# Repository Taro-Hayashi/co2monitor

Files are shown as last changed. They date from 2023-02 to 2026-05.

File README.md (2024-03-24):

# CO2モニター自作キット ビルドガイド
- [キット内容](#キット内容)
- [はんだ付け](#はんだ付け)
- [組み立て](#組み立て)
- [その他](#その他)

## キット内容
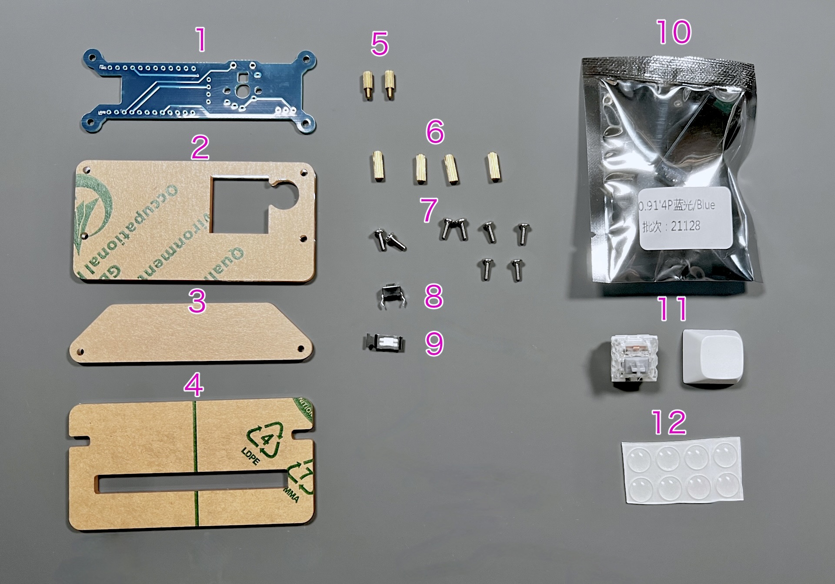
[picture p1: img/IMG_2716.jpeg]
 
||部品名|数||
|-|-|-|-|
|1|メインボード|1||
|2|トッププレート|1||
|3|ボトムプレート|1||
|4|スタンド|1||
|5|スペーサー（短）|2|M2 6mm|
|6|スペーサー（長）|4|M2 9mm|
|7|ねじ|8|M2|
|8|リセットスイッチ|1||
|9|LED|1|SK6812MINI-E|
|10|OLED|1|SSD1306|
|11|キースイッチ|1||
|12|キーキャップ|1||
|13|ゴム足|8||

### キット以外に必要なもの
|部品名|数||
|-|-|-|
|Pro Micro（Micro-B/Type-C）|1||
|MG-812使用CO2ガスセンサアンプキット|1|[秋月電子通商](https://akizukidenshi.com/catalog/g/gK-16446/)|
|USB ケーブル|1|各種キーボードショップ、100円均一など|

## はんだ付け
LEDをメインボード裏面にはんだ付けします。欠けがある方向と折れ曲がった白線が一致するようにしてください。
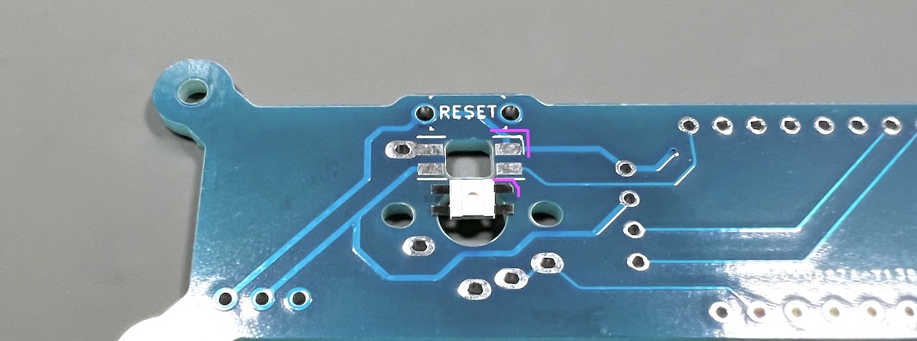
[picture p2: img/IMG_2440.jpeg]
 
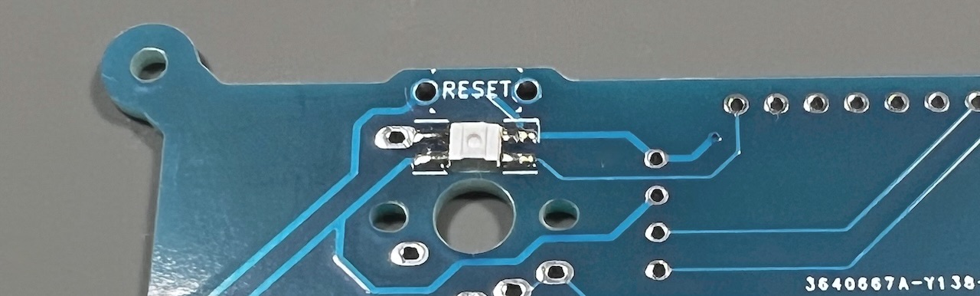
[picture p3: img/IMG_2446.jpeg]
 
リセットスイッチを裏面から差し込みはんだ付けします。
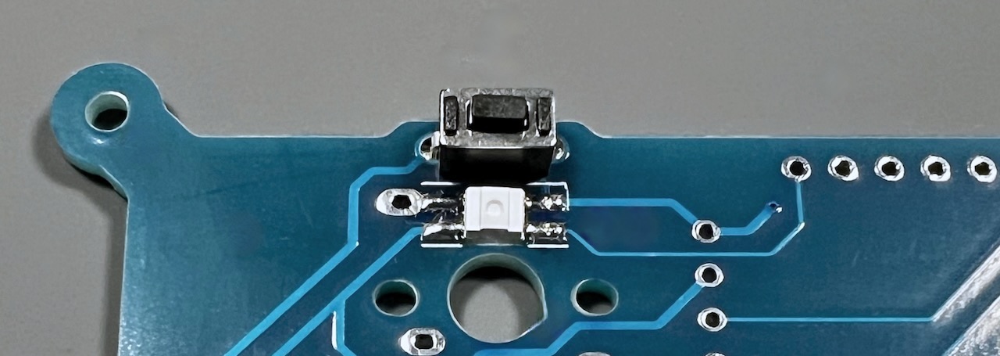
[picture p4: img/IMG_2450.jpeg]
 
Pro Microを付属のピンヘッダーで取り付けて両面をはんだ付けします。
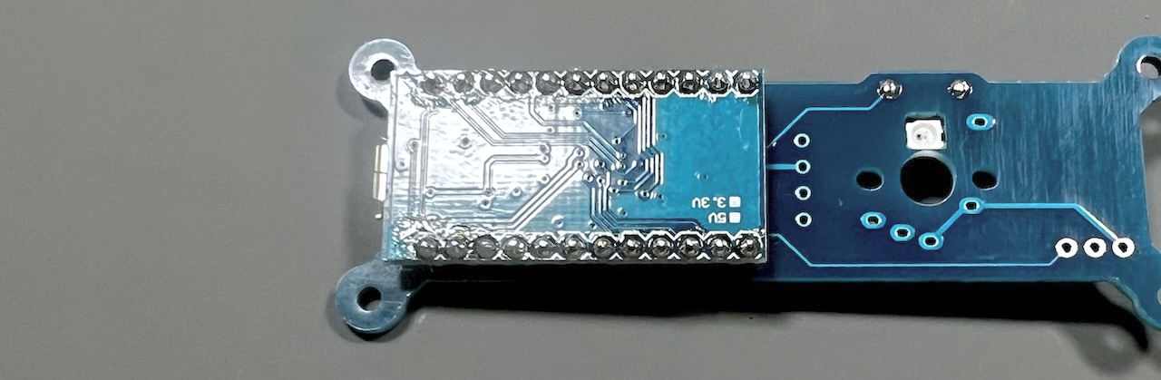
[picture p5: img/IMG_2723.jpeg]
 
付属、もしくはお好みのキースイッチを表面に差し込みはんだ付けします。
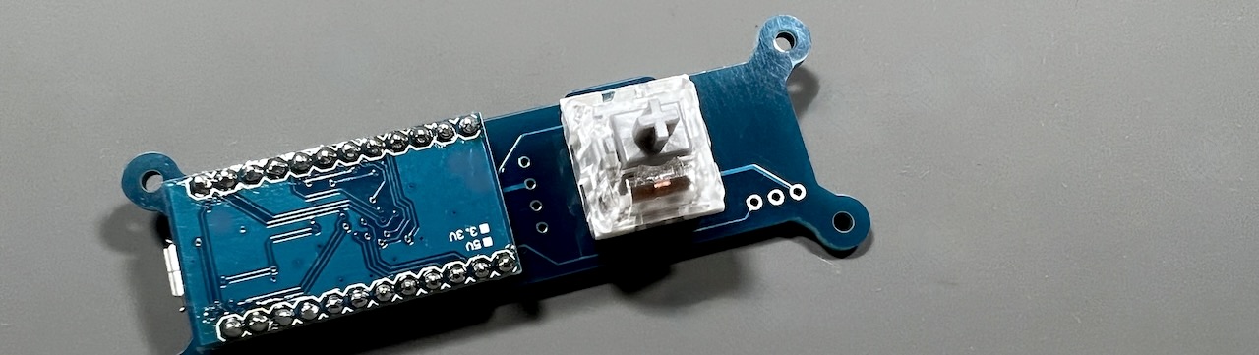
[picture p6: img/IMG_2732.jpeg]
 
MG-812使用CO2ガスセンサアンプキットを組み立てます。
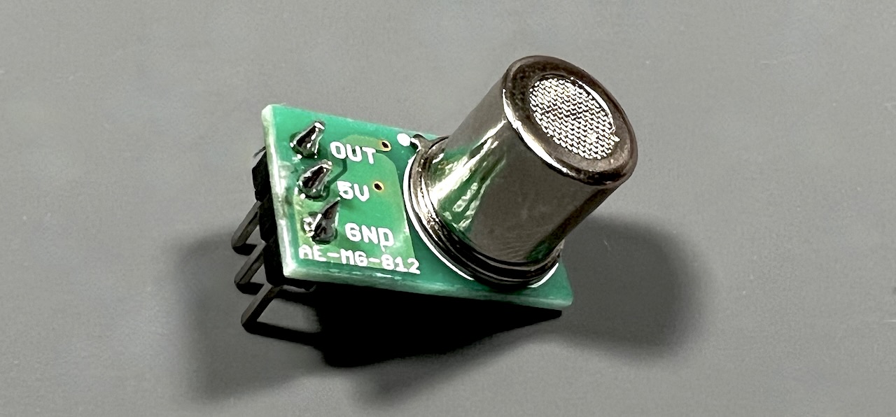
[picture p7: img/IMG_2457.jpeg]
 

> [!IMPORTANT] 
> 熱に弱い部品が使われているので熱しすぎないようにしてください。

OLEDはピンヘッダがはんだ付けされた状態でパッケージングされています。保護フィルムを剥がします。
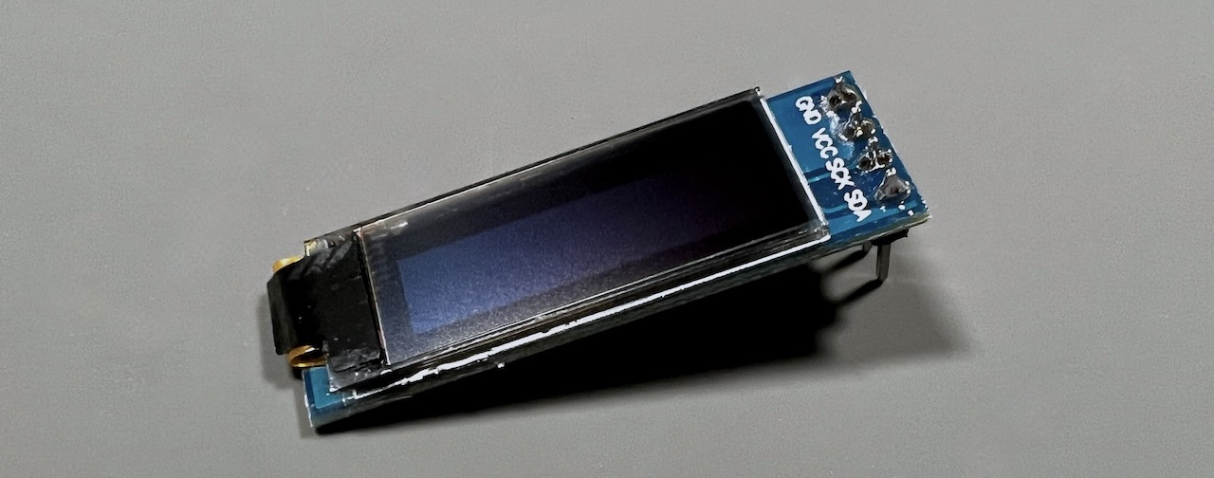
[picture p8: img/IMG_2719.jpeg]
 
２カ所にゴム足を貼ります。　　
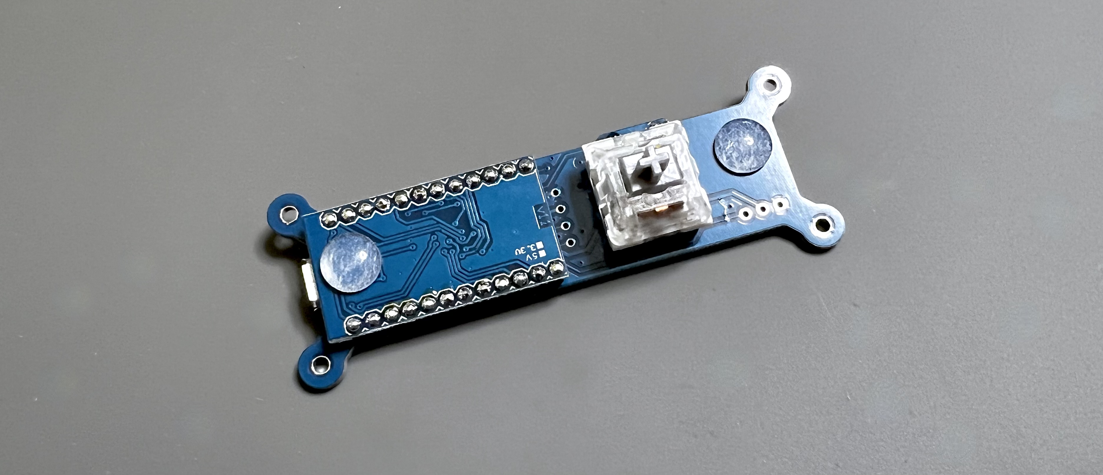
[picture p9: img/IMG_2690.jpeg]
 
OLEDとMG-812をメインボードにはんだ付けします。
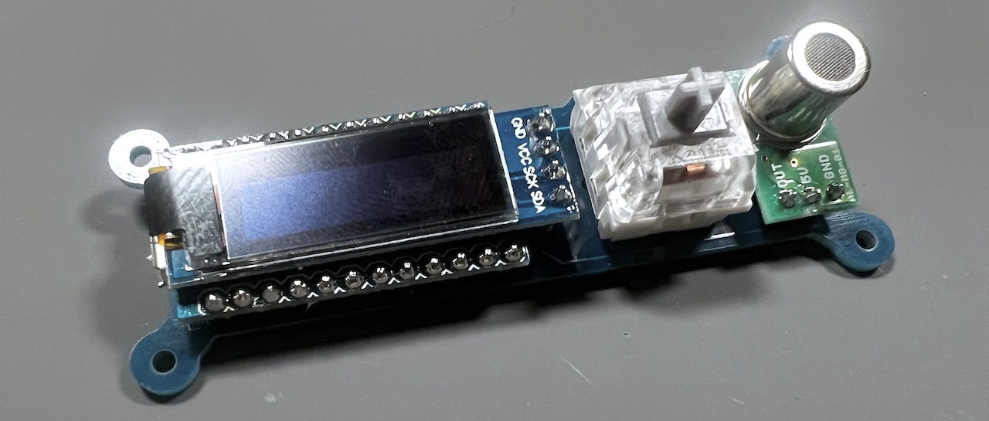
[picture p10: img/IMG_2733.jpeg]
 
動作の確認をするためにUSBケーブルでPCと接続しましょう。

### 動作テスト
ファームウェアを書き込みます。こちらのファイルをダウンロードしてください。
- [tarohayashi_co2monitor_default.hex](https://github.com/Taro-Hayashi/co2monitor/releases/latest/download/tarohayashi_co2monitor_default.hex)

こちらのサイトにGoogle ChromeでアクセスするとWebブラウザ経由で書き込むことができます。
- https://sekigon-gonnoc.github.io/promicro-web-updater/index.html

もしくはQMK Toolboxを使ってファームウェアを書き込んでください。
- [QMK Toolboxを使ったファームウェア更新方法](firmware.md)

少し待ちディスプレイに数字が表示され、キーを押してLEDの発光方法が変わればはんだ付けに成功しています。
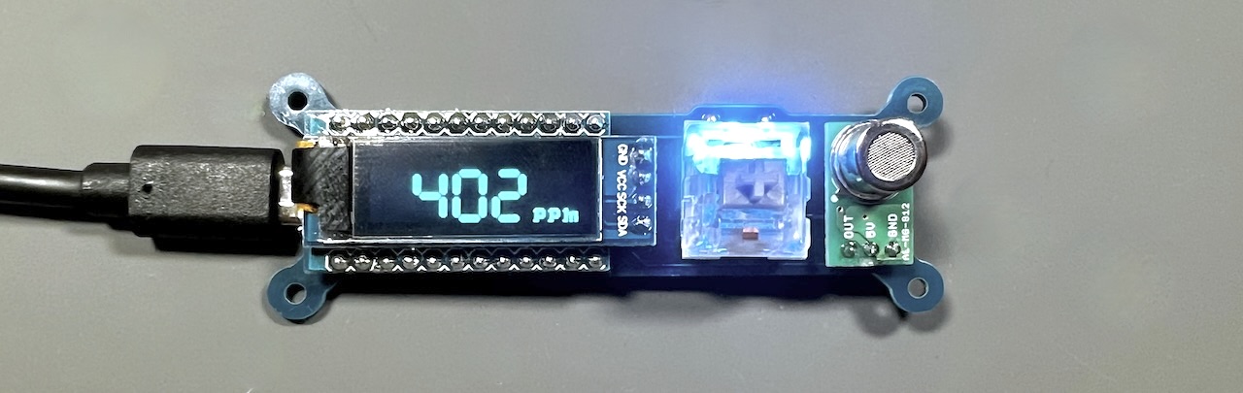
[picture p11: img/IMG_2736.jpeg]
 
> [!NOTE] 
> 数値が8888で固定されてしまうことがあります。これはMG-812にエージングが必要な個体が存在するためです。数日起動したままにすると徐々に性能が発揮されるようになります。

## 組み立て
USBケーブルを抜いてプレートを組付けます。  
メインボードにスペーサーを取り付けます。
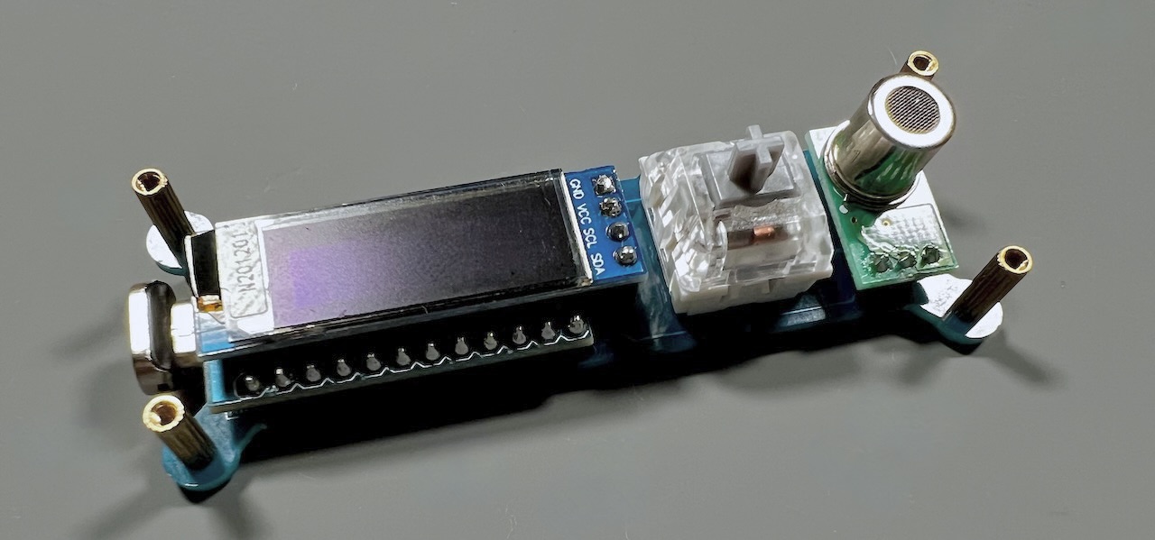
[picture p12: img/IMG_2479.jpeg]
 
表面の4箇所にスペーサー（長）を差し込み、裏面は写真のようにネジとスペーサー（短）で止めます。
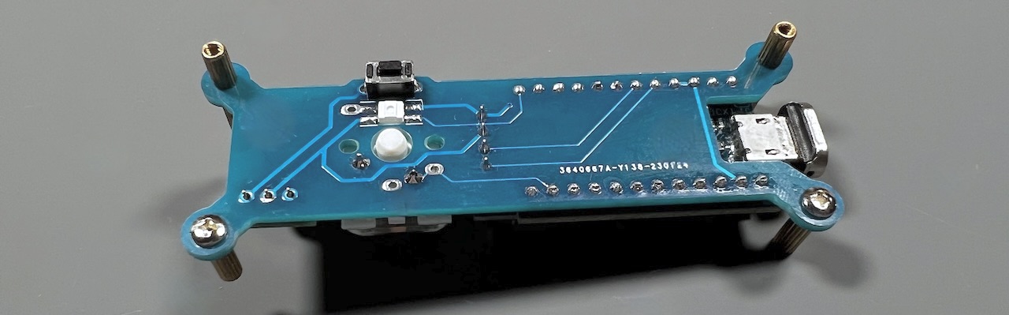
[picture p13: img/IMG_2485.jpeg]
 
トッププレートをねじ止めします。
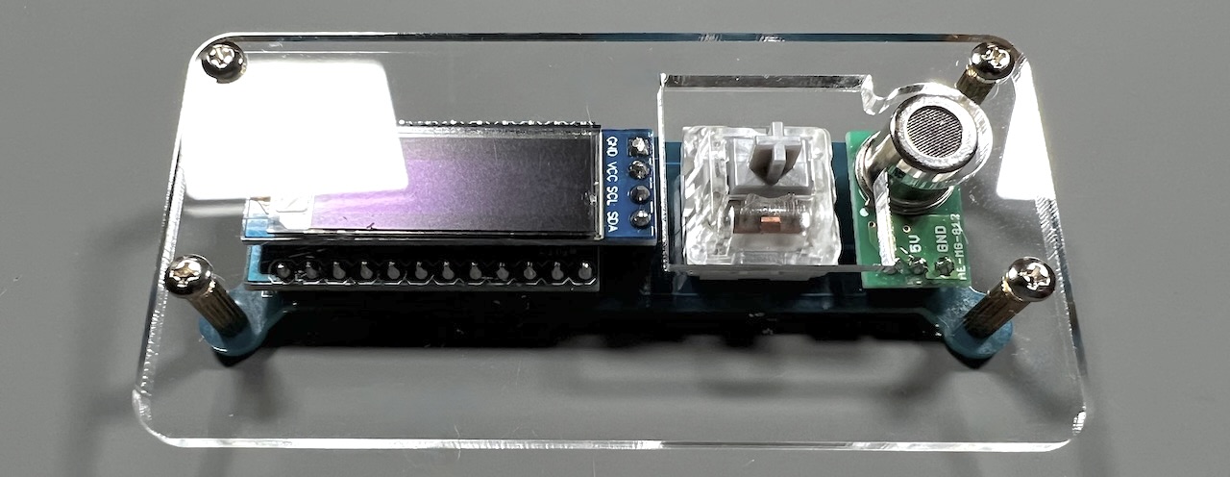
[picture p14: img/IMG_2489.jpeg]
 
ボトムプレートをねじで取り付けてゴム足を貼り付けたら完成です。
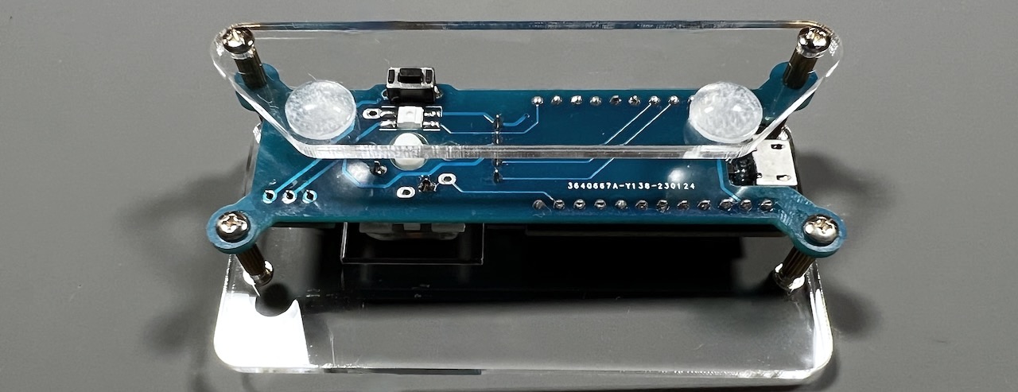
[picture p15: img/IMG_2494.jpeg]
 
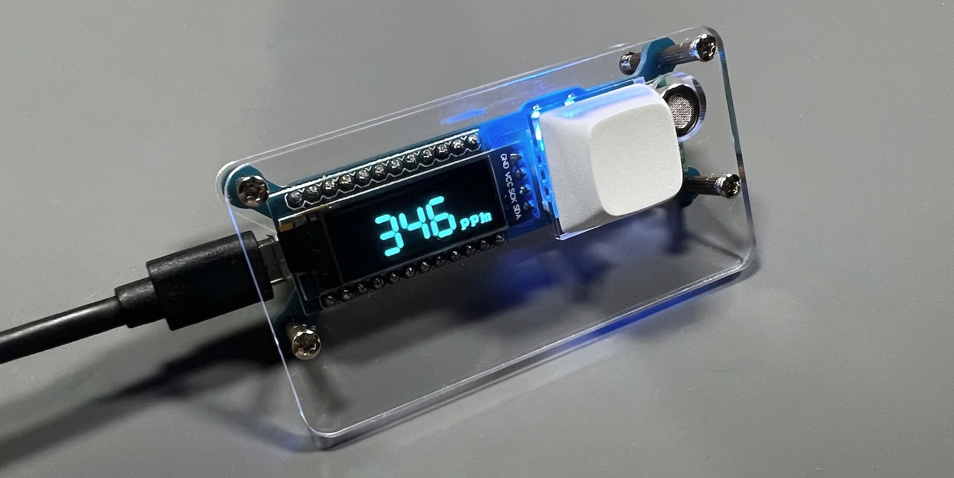
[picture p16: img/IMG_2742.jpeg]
 
お好みでスタンドをお使いください。
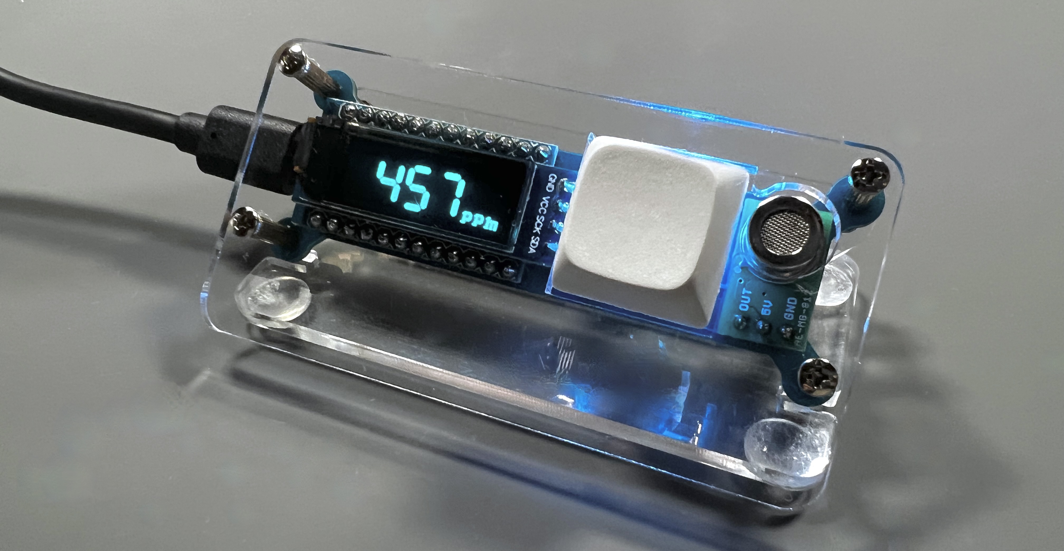
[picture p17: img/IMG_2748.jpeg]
 
USBケーブルをPCやUSB充電器などに接続して好きなところに置いてください。  

## 機能
スイッチを押すとLEDの光り方が切り替わります。  

|発光モード||
|-|-|
|GRADATION|ppmでLEDの色が段階的に変わります|
|THRESHOLD|設定された濃度になったら赤く光ります（初期設定：2000ppm)|
|OFF|LEDを光らなくします。|

また、スイッチを1秒以上押し続けてから離すと内部の状態をリセットできます。  
リセットは3日ごとに自動的にかかるようにしています。

## ご注意
- CO2センサーは発熱します。触り続けると低温やけどを引き起こすのでご注意ください。  
- 表示される数値は正確な濃度ではありません。換気された部屋を400ppmとした目安の値です。  
- PCのUSBからの電力供給は負荷やスリープなどで安定しないので動作確認後はUSB充電器への接続がおすすめです。  

### ファームウェアのコード
https://github.com/Taro-Hayashi/qmk_firmware/tree/tarohayashi/keyboards/tarohayashi/co2monitor

### 販売サイト
- BOOTH: https://tarohayashi.booth.pm/items/4500742

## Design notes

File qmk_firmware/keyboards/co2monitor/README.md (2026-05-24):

# CO2モニター自作キット
- Manual: https://github.com/Taro-Hayashi/co2monitor/blob/main/README.md
- BOOTH: https://tarohayashi.booth.pm/items/4500742
  
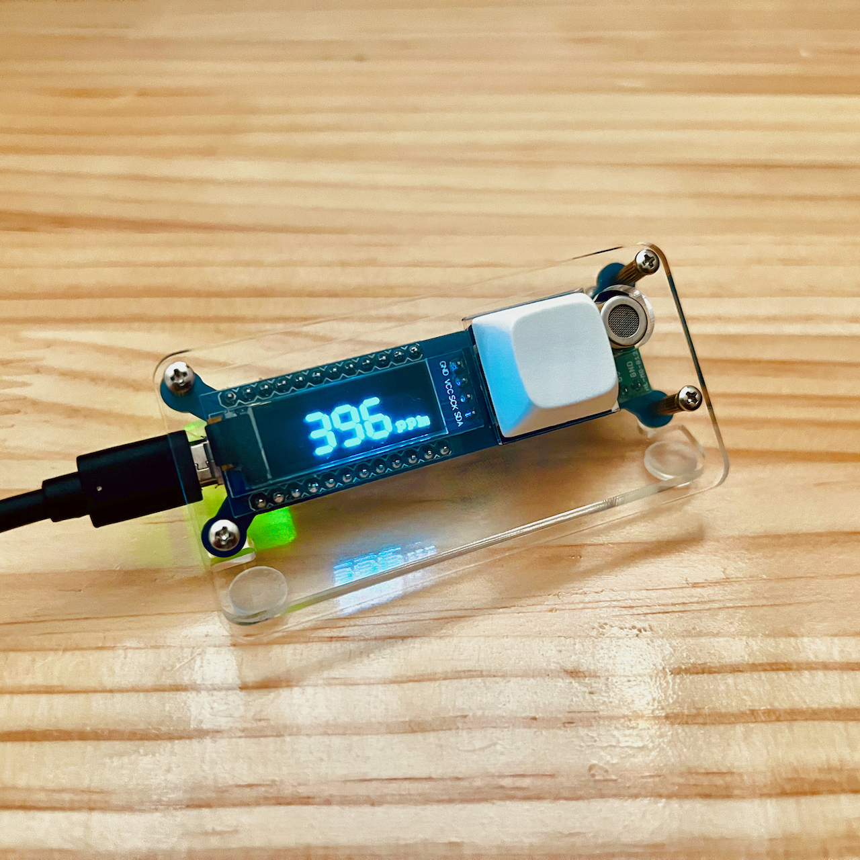
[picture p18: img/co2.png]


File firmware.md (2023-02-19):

# QMK Toolboxを使ったファームウェア更新方法

QMK Toolboxをダウンロードします。
- https://github.com/qmk/qmk_toolbox/releases

ファームウェアのファイルを開きリセットボタンを押すと、Flashのボタンが出てくるので押します。

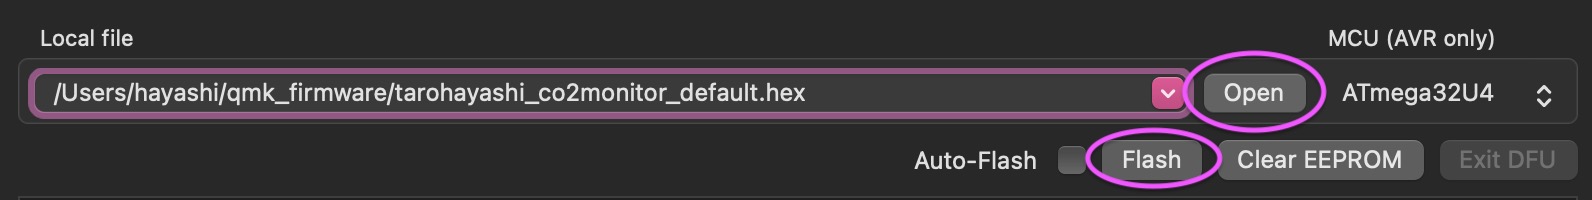
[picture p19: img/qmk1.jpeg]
 
更新終了です。

 
ブラウザの機能で戻ってください。

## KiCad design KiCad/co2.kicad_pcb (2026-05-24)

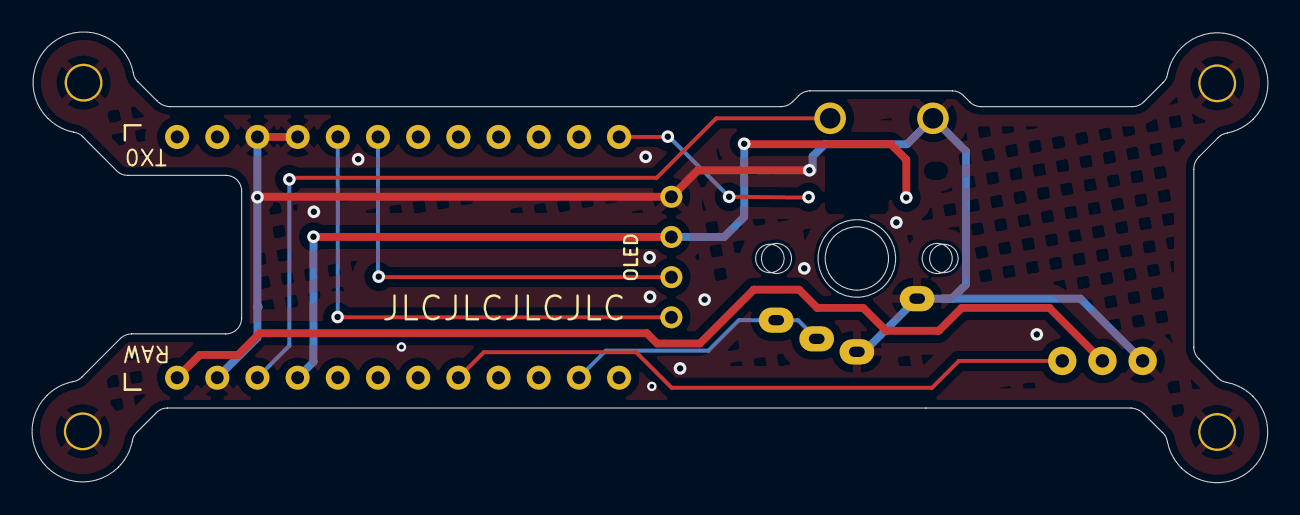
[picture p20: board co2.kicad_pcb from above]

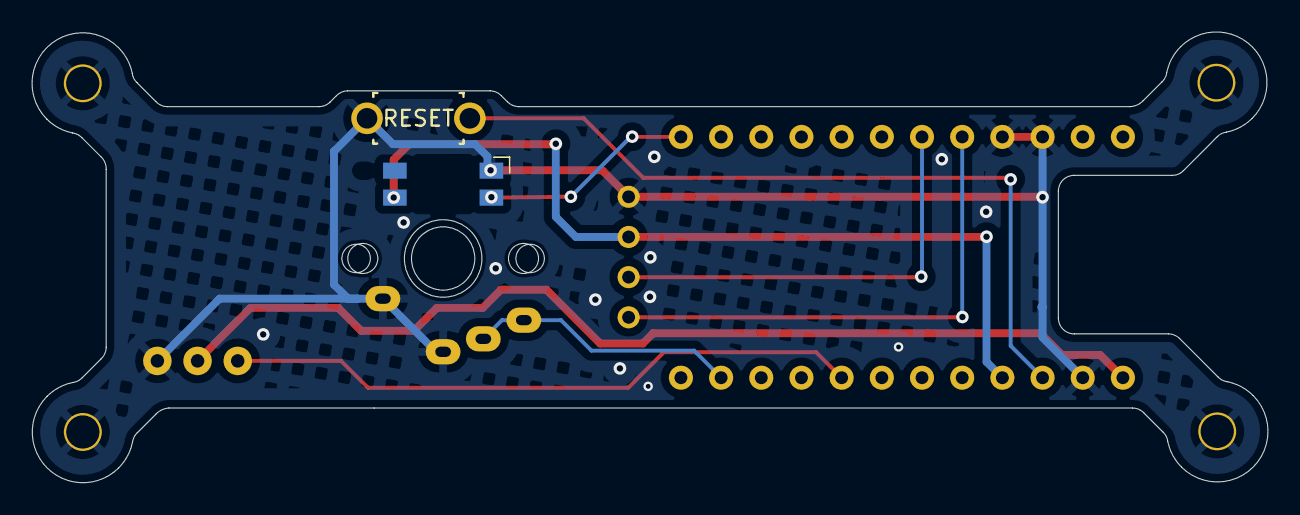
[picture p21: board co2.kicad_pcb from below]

Board: 2 copper layers, 78.1 x 28.5 mm, 11 parts (2 on the bottom side), 9 nets.

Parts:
BL1: YS-SK6812MINI-E; LED_SK6812MINI-E_Backlight
H1, H2, H3, H4: Hole; Hole_2mm_M2_PTH
OL1: OLED
RST1: ResetSW
SW1: SW_PUSH; CherryMX_1u
SW2: SW_PUSH; ChocV2_1u
U1: ProMicro
co1: MG812; DIP-MG812

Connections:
5v: U1.24 (RAW), co1.2 (5V)
GND: BL1.3 (VSS), H1.1, H2.1, H3.1, H4.1, OL1.4 (GND), RST1.2, SW1.2, SW2.2, U1.3 (GND), U1.4 (GND), U1.23 (GND), co1.3 (GND)
SCL: OL1.2 (SCL), U1.6 (3/D0/SCL)
SDA: OL1.1 (SDA), U1.5 (2/D1/SDA)
VCC: BL1.1 (VDD), OL1.3 (VCC), U1.21 (VCC)
co2: U1.17 (F7/A0), co1.1 (OUT)
led: BL1.4 (DIN), U1.12 (9/B5)
reset: RST1.1, U1.22 (RST)
sw: SW1.1, SW2.1, U1.14 (B2/16)
